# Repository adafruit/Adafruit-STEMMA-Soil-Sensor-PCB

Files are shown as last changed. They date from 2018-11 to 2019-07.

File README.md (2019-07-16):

## Adafruit STEMMA Soil Sensor - I2C Capacitive Moisture Sensor PCB

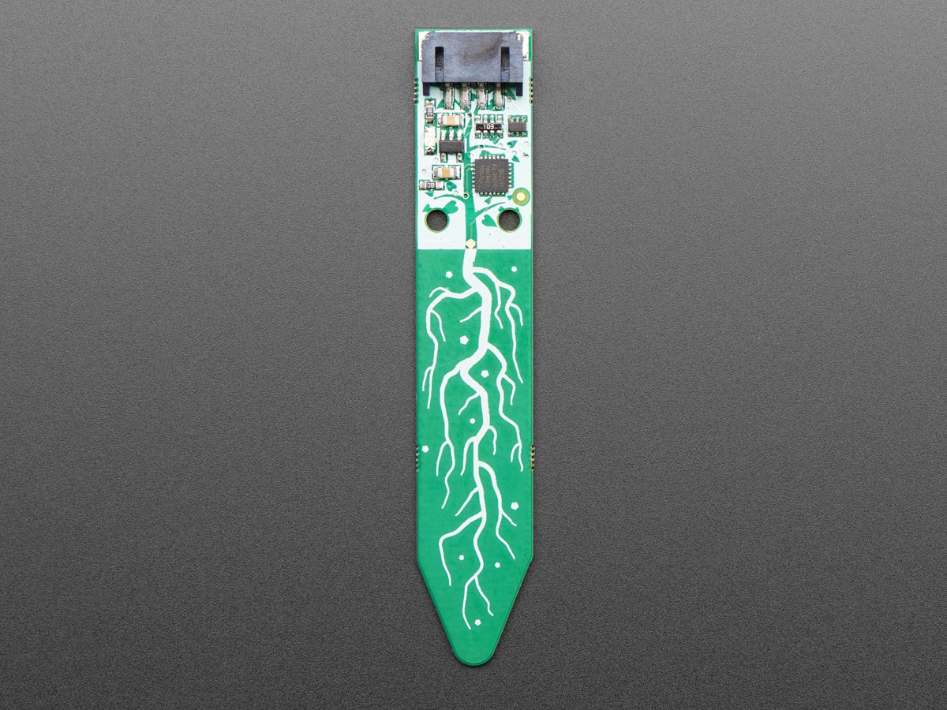
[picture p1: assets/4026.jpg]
<a href="http://www.adafruit.com/products/4026"><br/>
Click here to purchase one from the Adafruit shop</a>

PCB files for the Adafruit STEMMA Soil Sensor - I2C Capacitive Moisture Sensor. Format is EagleCAD schematic and board layout
* https://www.adafruit.com/product/4026

### Description

Most low cost soil sensors are resistive style, where there's two prongs and the sensor measures the conductivity between the two. These work OK at first, but eventually start to oxidize because of the exposed metal. Even if they're gold plated! The resistivity measurement goes up and up, so you constantly have to re-calibrate your code. Also, resistive measurements don't always work in loose soil.

This design is superior with a **capacitive** measurement. Capacitive measurements use only one probe, don't have any exposed metal, and don't introduce any DC currents into your plants. We use the built in capacitive touch measurement system built into the ATSAMD10 chip, which will give you a reading ranging from about 200 (very dry) to 2000 (very wet). As a bonus, we also give you the ambient temperature from the internal temperature sensor on the microcontroller, it's not high precision, maybe good to + or - 2 degrees Celsius.

To make it so you can use the sensor with just about any microcontroller, we have an I2C interface. Connect a 4-pin JST-PH cable (we have a few stocked) to your microcontroller or single board computer to 3-5V power, Ground, I2C SDA and I2C SCL and [then run our Arduino or CircuitPython code to read the temperature and capacitive measurement](https://learn.adafruit.com/adafruit-stemma-soil-sensor-i2c-capacitive-moisture-sensor). No soldering required!

**Please note: This is just the sensor, you'll also need a JST 4-PH cable to go along for plugging it in!** We have a few options such as one with [male header pins](https://www.adafruit.com/product/3955), [female header pins](https://www.adafruit.com/product/3950), and a [JST-JST cable](https://www.adafruit.com/product/3568). You can use Seeed Grove cables and boards to connect - the Grove cable is a little different looking but will fit just fine.

[Check out the full guide for schematics, wiring, code and more!](https://learn.adafruit.com/adafruit-stemma-soil-sensor-i2c-capacitive-moisture-sensor)

### License

Adafruit invests time and resources providing this open source design, please support Adafruit and open-source hardware by purchasing products from [Adafruit](https://www.adafruit.com)!

Designed by Limor Fried/Ladyada for Adafruit Industries.

Creative Commons Attribution/Share-Alike, all text above must be included in any redistribution. See license.txt for additional details.

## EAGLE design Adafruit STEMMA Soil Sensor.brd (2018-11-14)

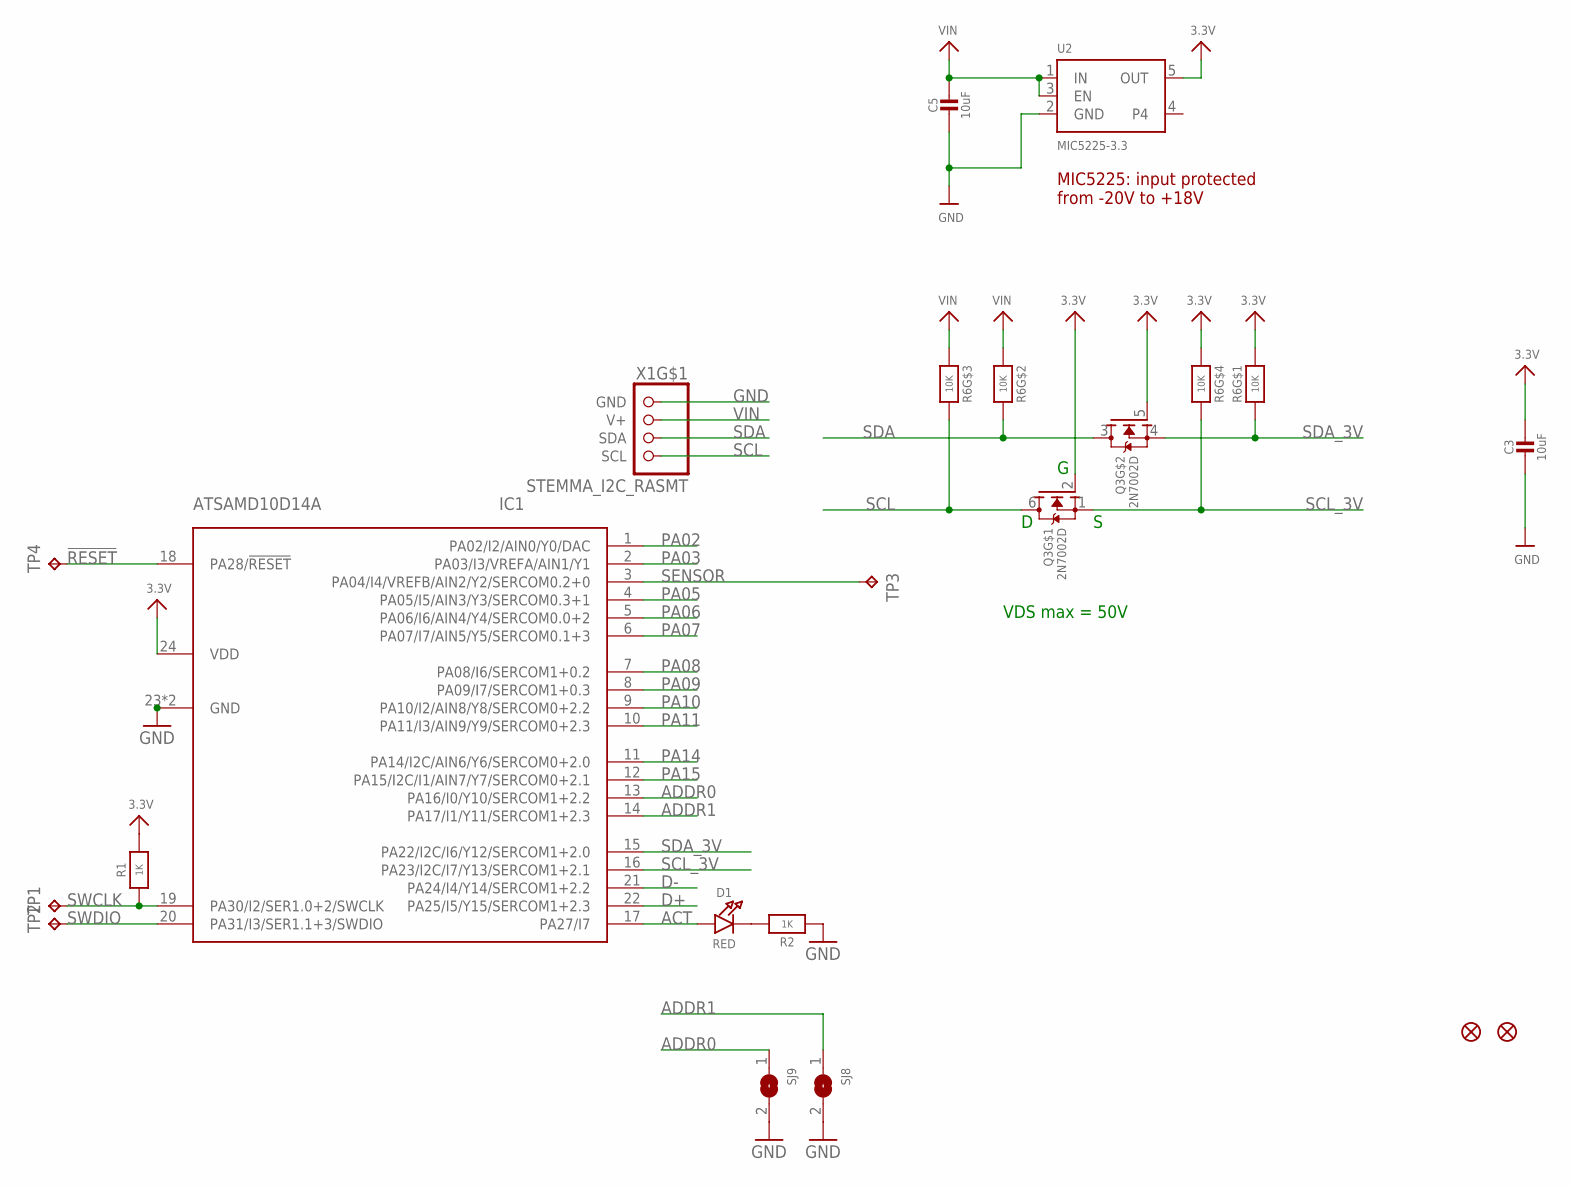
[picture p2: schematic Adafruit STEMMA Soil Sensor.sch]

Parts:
C3, C5: 10uF; 0805-NO
D1: RED; CHIPLED_0805_NOOUTLINE
FID1, FID2: FIDUCIAL_1MM
IC1: ATSAMD10D14A; QFN24_4MM
Q3: 2N7002D; SOT363
R1, R2: 1K; 0603-NO
R6: 10K; RESPACK_4X0603
SJ8, SJ9: SOLDERJUMPER; SOLDERJUMPER_ARROW_NOPASTE
TP1, TP2, TP4: TPTP15R; TP15R
TP3: TPTP10R; TP10R
U2: MIC5225-3.3; SOT23-5
X1: STEMMA_I2C_RASMT; JSTPH4

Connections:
3.3V: C3.1, IC1.24 (VDD), Q3.2 (G), Q3.5 (G), R1.2, R6.1, R6.5 (2), U2.5 (OUT)
!RESET: IC1.18 (PA28/!RESET), TP4.TP
ACT: D1.A, IC1.17 (PA27/I7)
ADDR0: IC1.13 (PA16/I0/Y10/SERCOM1+2.2), SJ9.1
ADDR1: IC1.14 (PA17/I1/Y11/SERCOM1+2.3), SJ8.1
D+: IC1.22 (PA25/I5/Y15/SERCOM1+2.3)
D-: IC1.21 (PA24/I4/Y14/SERCOM1+2.2)
GND: C3.2, C5.2, IC1.23 (GND), IC1.THERM (GND), R2.1, SJ8.2, SJ9.2, U2.2 (GND), X1.1 (GND)
unnamed: D1.C, R2.2
PA02: IC1.1 (PA02/I2/AIN0/Y0/DAC)
PA03: IC1.2 (PA03/I3/VREFA/AIN1/Y1)
PA05: IC1.4 (PA05/I5/AIN3/Y3/SERCOM0.3+1)
PA06: IC1.5 (PA06/I6/AIN4/Y4/SERCOM0.0+2)
PA07: IC1.6 (PA07/I7/AIN5/Y5/SERCOM0.1+3)
PA08: IC1.7 (PA08/I6/SERCOM1+0.2)
PA09: IC1.8 (PA09/I7/SERCOM1+0.3)
PA10: IC1.9 (PA10/I2/AIN8/Y8/SERCOM0+2.2)
PA11: IC1.10 (PA11/I3/AIN9/Y9/SERCOM0+2.3)
PA14: IC1.11 (PA14/I2C/AIN6/Y6/SERCOM0+2.0)
PA15: IC1.12 (PA15/I2C/I1/AIN7/Y7/SERCOM0+2.1)
SCL: Q3.6 (D), R6.6 (2), X1.4 (SCL)
SCL_3V: IC1.16 (PA23/I2C/I7/Y13/SERCOM1+2.1), Q3.1 (S), R6.4 (1)
SDA: Q3.3 (D), R6.7 (2), X1.3 (SDA)
SDA_3V: IC1.15 (PA22/I2C/I6/Y12/SERCOM1+2.0), Q3.4 (S), R6.8 (2)
SENSOR: IC1.3 (PA04/I4/VREFB/AIN2/Y2/SERCOM0.2+0), TP3.TP
SWCLK: IC1.19 (PA30/I2/SER1.0+2/SWCLK), R1.1, TP1.TP
SWDIO: IC1.20 (PA31/I3/SER1.1+3/SWDIO), TP2.TP
VIN: C5.1, R6.2 (1), R6.3 (1), U2.1 (IN), U2.3 (EN), X1.2 (V+)

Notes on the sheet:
MIC5225: input protected from -20V to +18V
VDS max = 50V

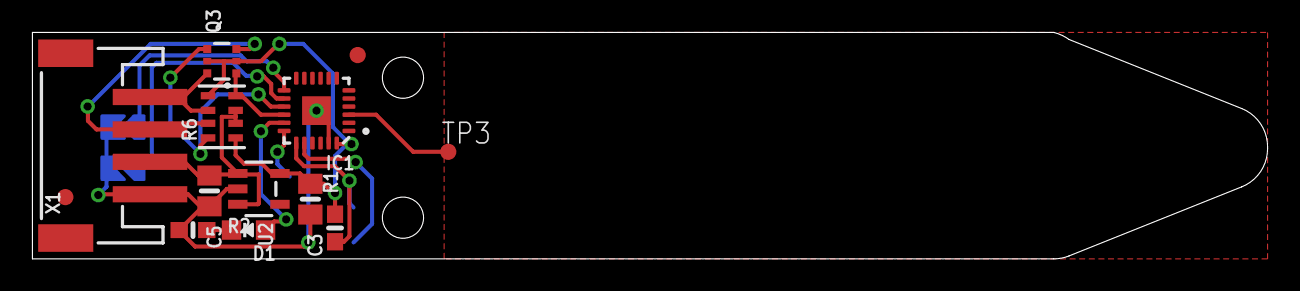
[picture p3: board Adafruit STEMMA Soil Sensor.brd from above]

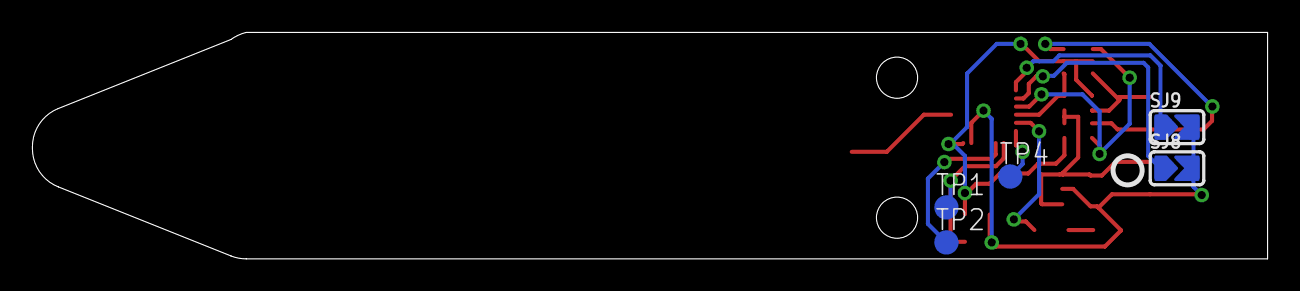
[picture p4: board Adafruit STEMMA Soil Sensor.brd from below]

Board: 2 copper layers, 76.2 x 14.0 mm, 21 parts (7 on the bottom side), 15 nets.

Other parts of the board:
U$4: STEMMA_SOIL_BOT
U$5: STEMMA_SOIL_TOP
U$12: PCBFEAT-REV-040

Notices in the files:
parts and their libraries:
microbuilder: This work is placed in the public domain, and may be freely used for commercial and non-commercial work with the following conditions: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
